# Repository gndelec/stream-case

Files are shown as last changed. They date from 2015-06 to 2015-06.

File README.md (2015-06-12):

# Myriad-RF STREAM board enclosure

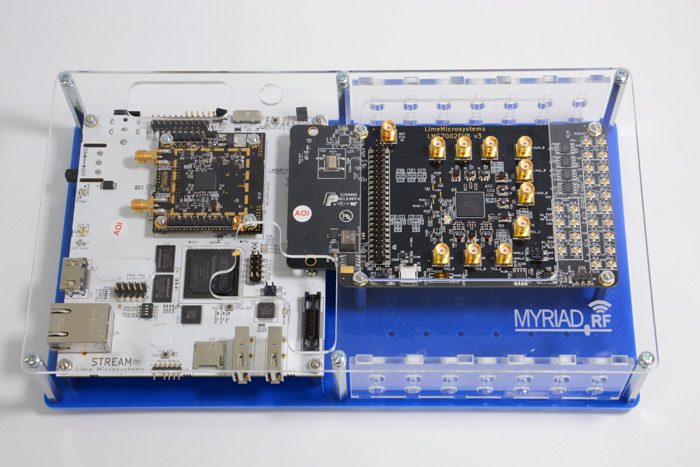
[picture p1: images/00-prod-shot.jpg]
MRFC-01 case


*Note: shown with 2x RF modules fitted, whereas only one at a time would be used in practice.*

An acrylic enclosure designed to accommodate the Myriad-RF STREAM board and an RF module. Features include:

* Hardware for secure mounting of boards
* Array of holes for panel mount SMA connectors
* Array of additional PEEK+ spaced holes for mounting other hardware

A complete kit of parts can be bought from [Ground Electronics](http://groundelectronics.com/products/).

## Repository contents

The case design is provided in the following formats:

* Inksacpe SVG (source)
* PDF
* DXF

The case parts are laser cut from 3mm sheet acrylic.

## Bill of materials

In addition to the acrylic parts the MRFC-01 kit contains:

| Qty | Item |
| --- | --- |
|  17 | M3 steel hex nut |
|  12 | M3 steel washer |
|  4  | M2.5 x 6mm steel machine screw |
|  2  | M2.5 x 15mm F-F hex standoff |
|  4  | M3 x 5mm F-F hex standoff |
|  4  | M3 x 15mm M-F hex standoff |
|  4  | M3 x 25mm M-F hex standoff |
|  6  | M3 x 40mm M-F hex standoff |
|  14 | M3 x 8mm steel machine screw |
|  4  | M3 x 12mm steel machine screw |
|  6  | Self Adhesive Rubber Bumpers |

## Other hardware required

- STREAM board
- [LMS7002EVB](http://www.digikey.co.uk/product-detail/en/UNITE7002/1434-1004-ND/5012881) or [Myriad-RF 1](https://myriadrf.org/projects/rdk/) module

## Assembly

Note that the STREAM board can be used standalone, or with an LMS7002EVB *or* Myriad-RF 1 module fitted. The photos in this repository show it with both of these fitted at the same time, however, this has not been tested and is not recommended! If using an RF module please following the instructions to fit one *or* the other.

### Common

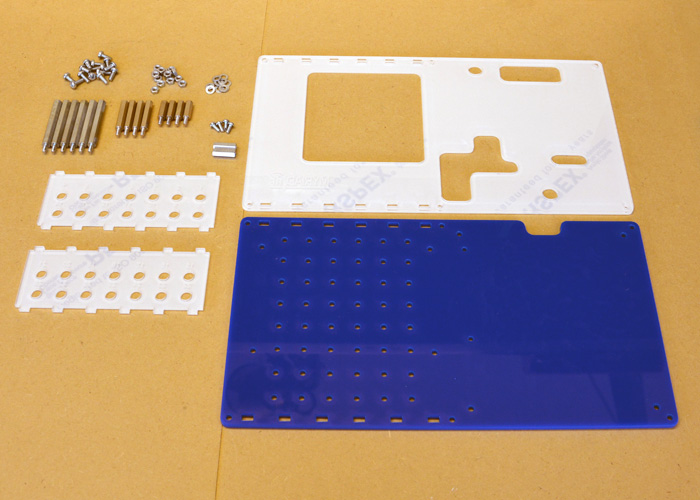
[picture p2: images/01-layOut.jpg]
Parts laid out


- Lay out all of the parts and ensure you have everything listed in the B.O.M.

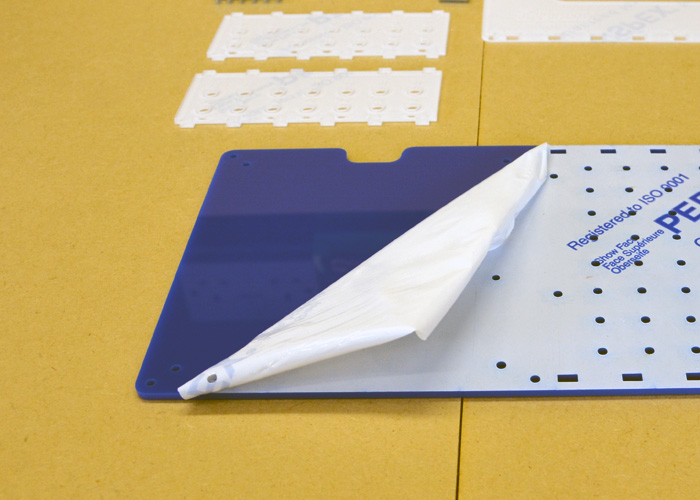
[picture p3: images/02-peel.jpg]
Peel off acrylic backing


- Remove the protective backing from the acrylic parts. Note that this is likely to generate static electricity and be not to do this near sensitive electronics. Wipe any clouding / marks from the acrylic that may have occured during manufacture.

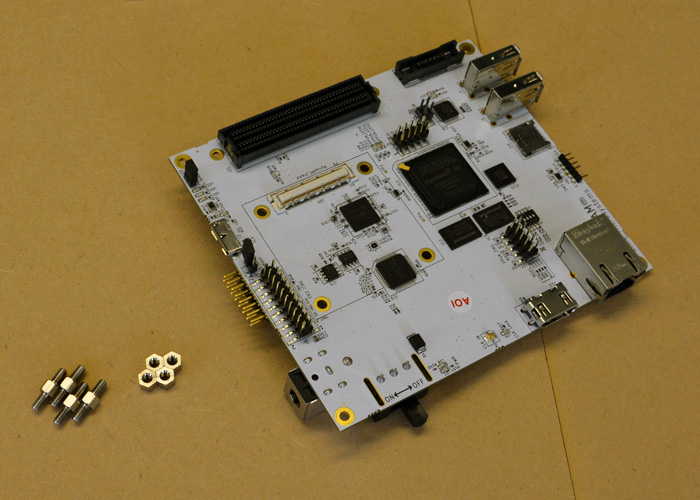
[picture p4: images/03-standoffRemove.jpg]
Standoff Remove


- Remove 4 x M3 x 4mm standoffs from STREAM board

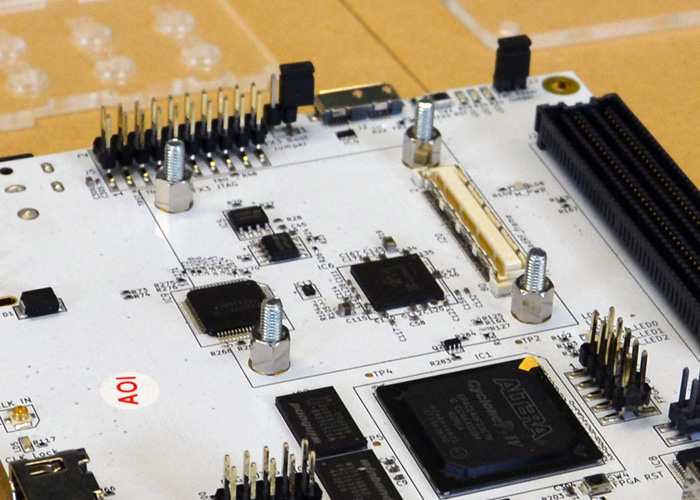
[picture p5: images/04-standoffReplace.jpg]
StandoffReplace


- Add 4 x M3 x 12mm screws + 4 x M3 x 5mm standoffs to replace the previous standoffs. Note M3 screws go through bottom of board, all the way through standoffs as shown in photo.

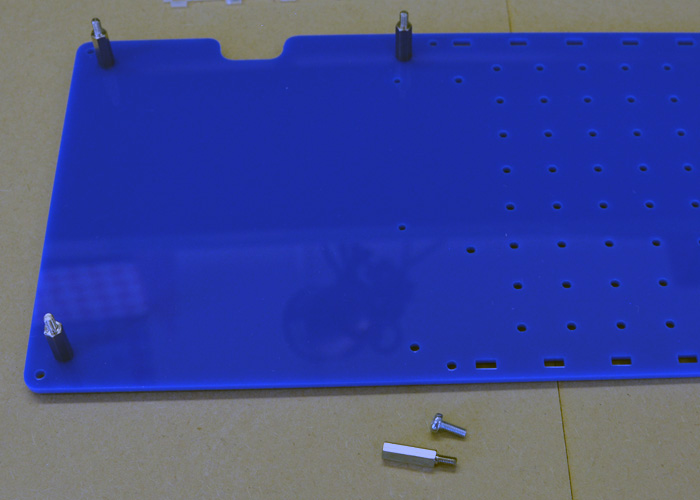
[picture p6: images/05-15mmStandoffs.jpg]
Standoffs


- Add 4 x M3 x 15mm M-F standoffs + 4 x M3 x 8mm screws to base.

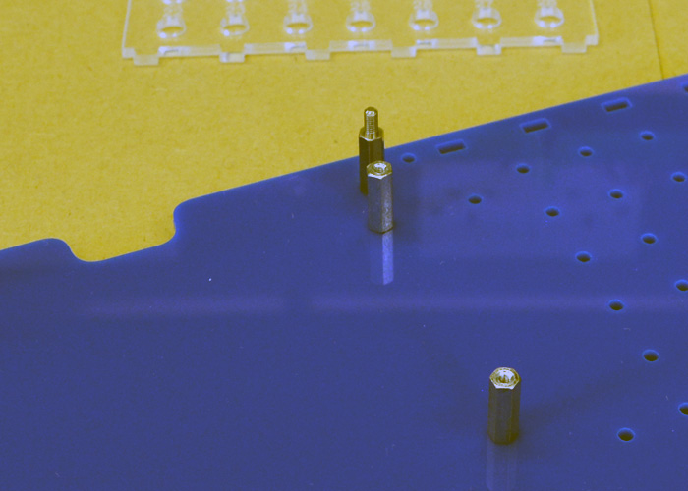
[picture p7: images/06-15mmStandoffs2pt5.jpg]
Standoffs


- Add 2 x M2.5 x 15mm F-F standoffs + 2 x M2.5 x 6mm screws to base.

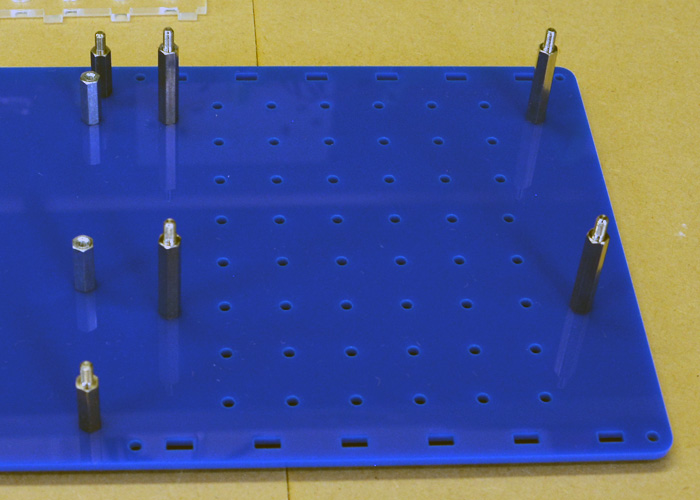
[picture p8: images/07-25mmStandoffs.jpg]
Standoffs


- Add 4 x M3 x 25mm M-F standoffs + 4 x M3 X 8mm screws to base.

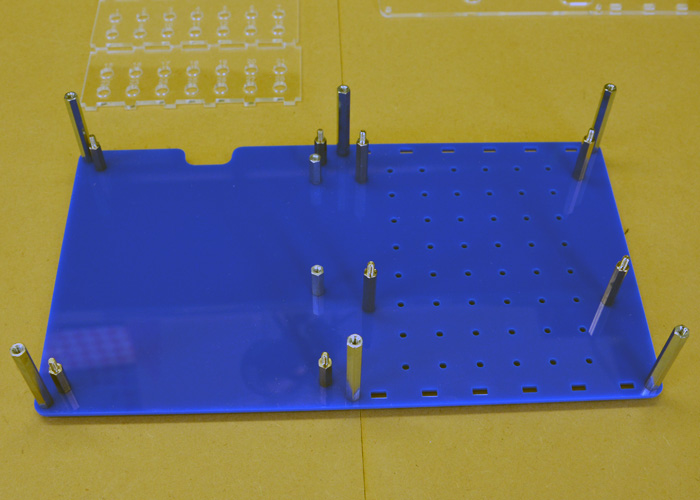
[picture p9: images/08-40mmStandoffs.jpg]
Standoffs


- Add 6 x M3 x 40mm standoffs + 6 x M3 hex nuts (Note these to be mounted opposite way up to other standoffs - male thread through base)

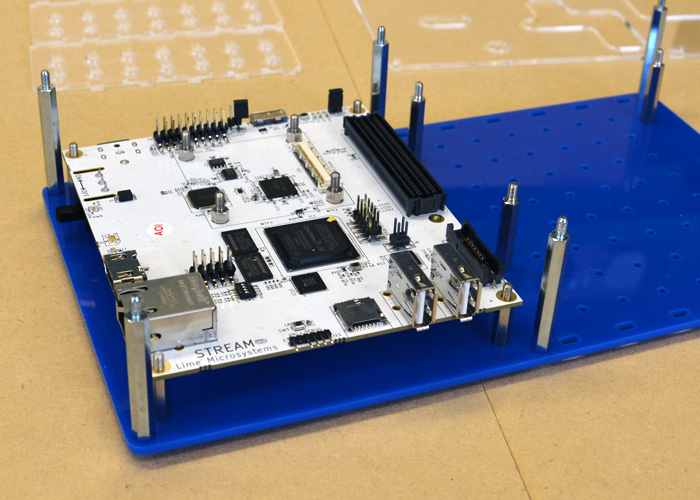
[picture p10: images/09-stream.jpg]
STREAM


- Place STREAM board onto 15mm standoffs.

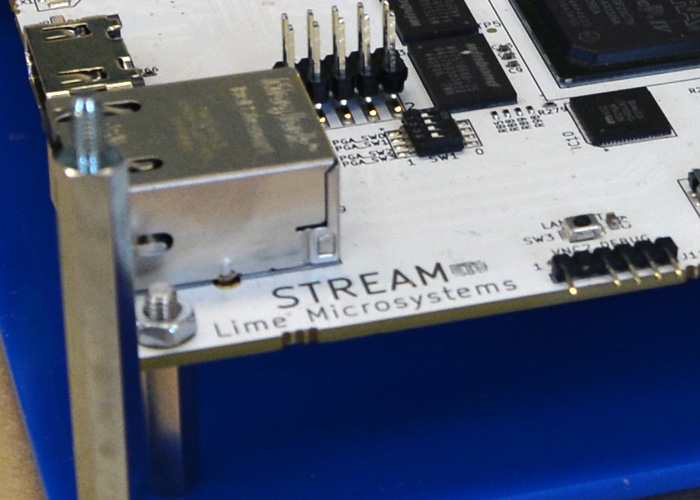
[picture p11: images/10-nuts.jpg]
nuts


- Add 4 x M3 hex nuts to hold STREAM board in place. Note to be careful not to overtighten.

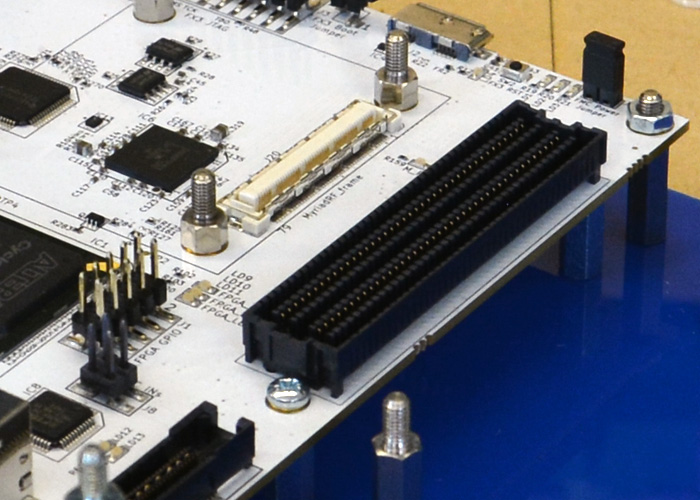
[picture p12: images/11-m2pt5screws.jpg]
screws


- Add 2 x M2.5 x 6mm screws through STREAM board, either side of the J21 connector.

** Note: The following steps are optional and which you follow will depend on which RF module you are using. Later photos show both boards fitted, but this has not been tested, is not advised and no responsibility will be accepted for any damage caused by applying power with both the LMS7002EVB and Myriad-RF 1 module fitted! **

### Use with LMS7002EVB (UNITE)

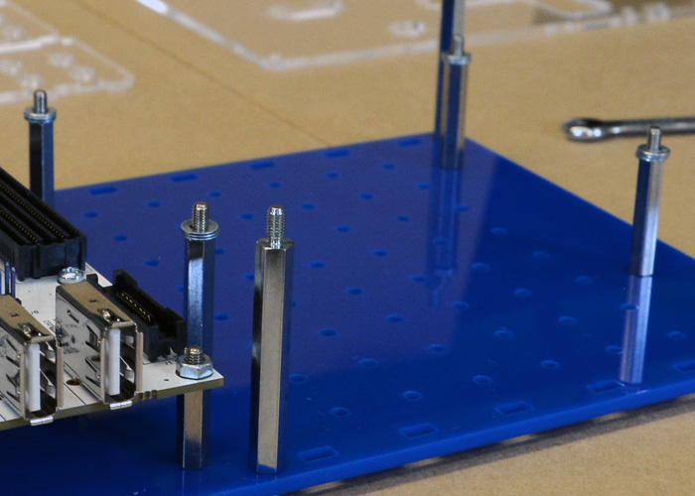
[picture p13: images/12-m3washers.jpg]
washers


- Add M3 washers to 4 x M3 x 25mm standoffs to get correct height for LMS7002EVB board (we found 2 or 3 per standoff to work well depending on the washers used).

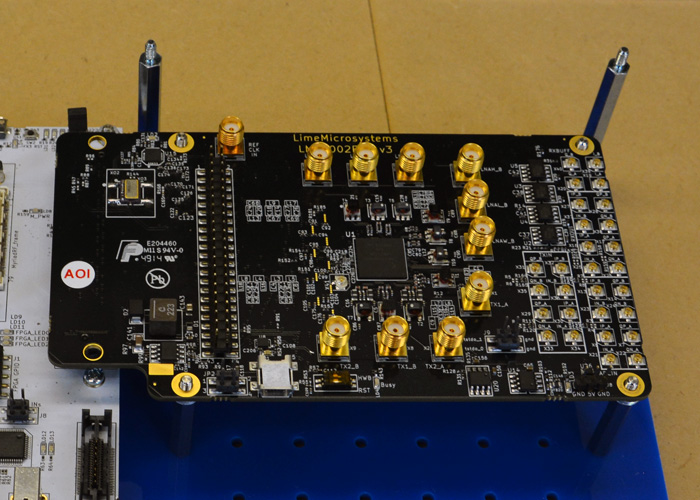
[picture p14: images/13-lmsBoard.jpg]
LMS7002EVB


- Add LMS7002EVB to M3 x 25mm standoffs + washers.

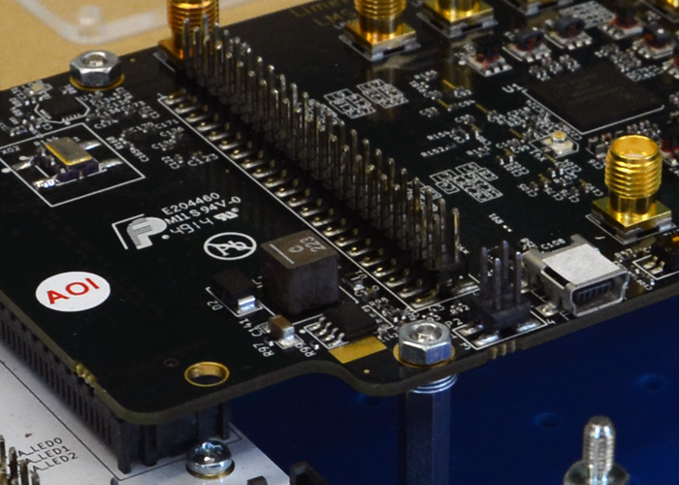
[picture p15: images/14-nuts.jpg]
nuts


- Add 4 x M3 hex nuts to hold LMS7002EVB in place. Again noting care to not overtighten.

### Use with Myriad-RF 1 module

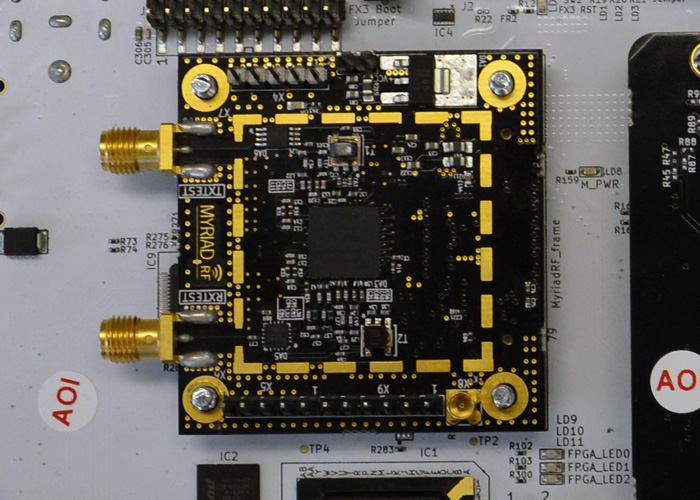
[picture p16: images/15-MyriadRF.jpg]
MyriadRF


- Add Myriad-RF module to STREAM board (Note that extra care should be taken due to the delicate nature of the connectors used)

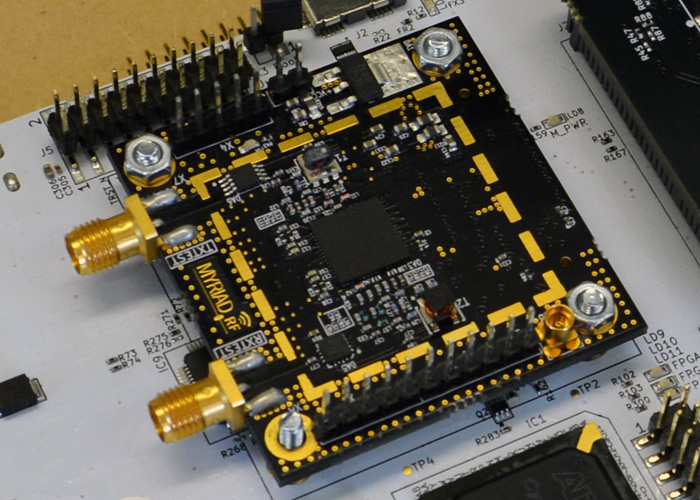
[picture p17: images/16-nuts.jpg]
nuts


- Add 3 x M3 hex nuts to hold Myriad-RF module in place (note that one corner does not allow for an M3 hex nut due insufficient clearance of nearby header)

### Completing case assembly

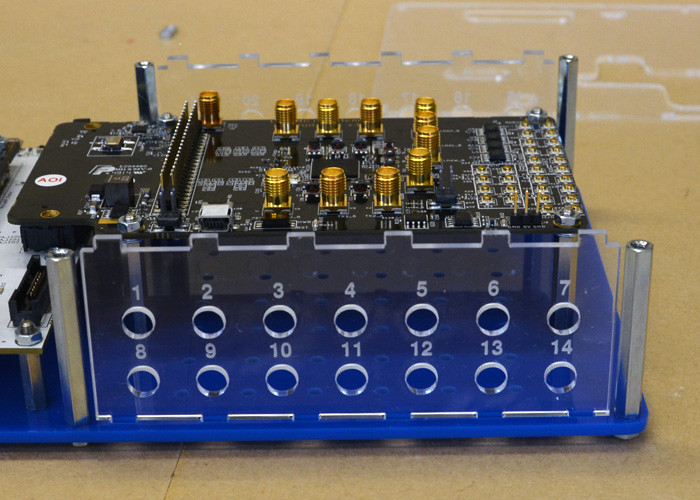
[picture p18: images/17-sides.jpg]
sides


- Add 2 x side pieces and optional breakout connectors / wire assemblies as needed (not included in kit)

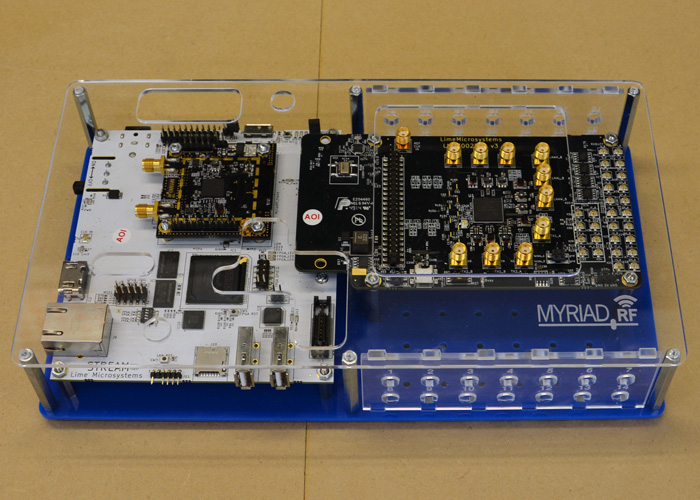
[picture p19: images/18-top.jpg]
top


- Add top plate to assembly

- Add 6 x M3 x 8mm screws to secure top plate in place.

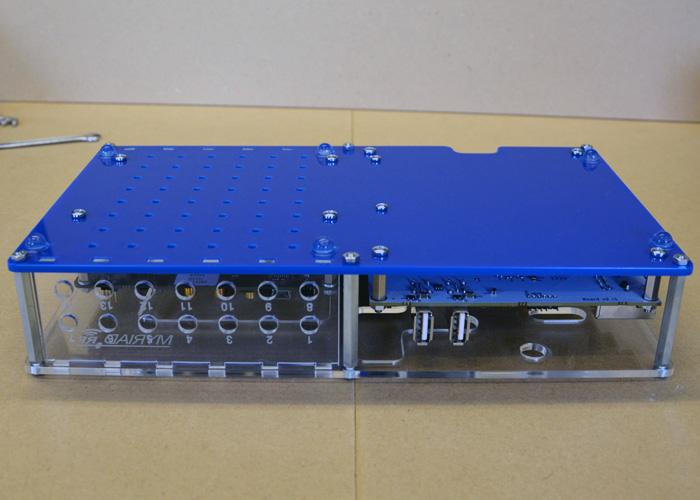
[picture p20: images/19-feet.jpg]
feet


- Turn the assembly over and stick the 6 x self adhesive rubber bumpers to the base.

## Notes

- The MRFC-01 case includes PEEK+ array (15mm) compatible hole spacing for easy addition of modules and hardware should you wish to exapnd your system. Note that we used 3mm holes to allow for use of M3 hardware and avoid the need for extra threaded push-fit parts.

- The MRFC-01 kit contains some extra units of the smaller hardware such as nuts and washers - do not be alarmed if there are some left over after completion of assembly!

## Changelog

| Version | Date | Summary
|---|---|---

## Licence

STREAM and Myriad-RF development case copyright 2015 [AB Open Ltd](http://abopen.com).

<br />This work is licensed under a <a rel="license" href="http://creativecommons.org/licenses/by/4.0/">Creative Commons Attribution 4.0 International License</a>.

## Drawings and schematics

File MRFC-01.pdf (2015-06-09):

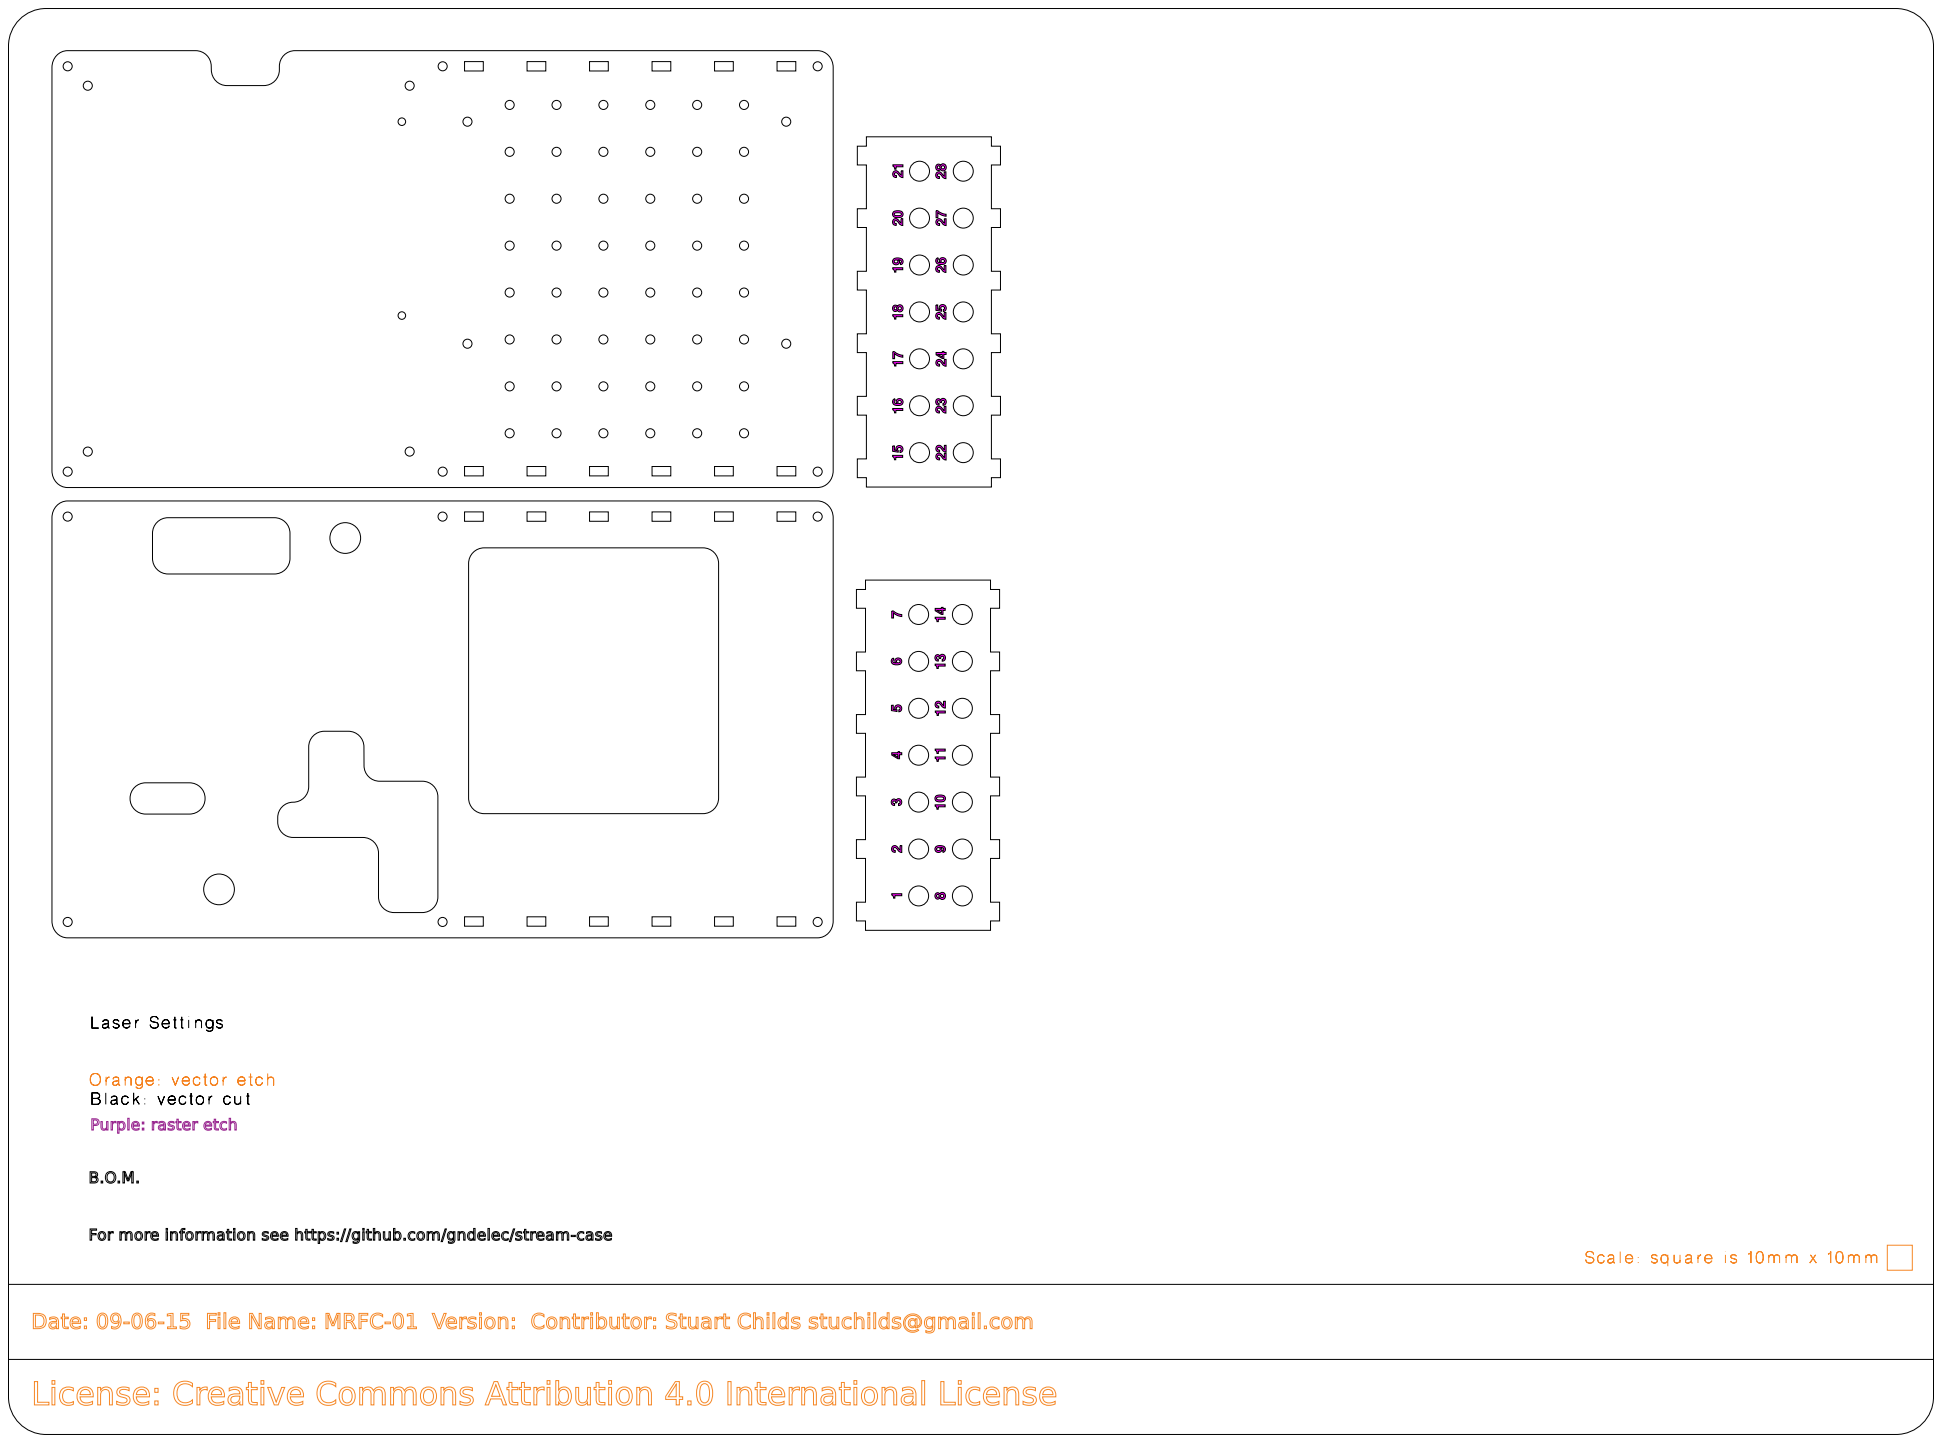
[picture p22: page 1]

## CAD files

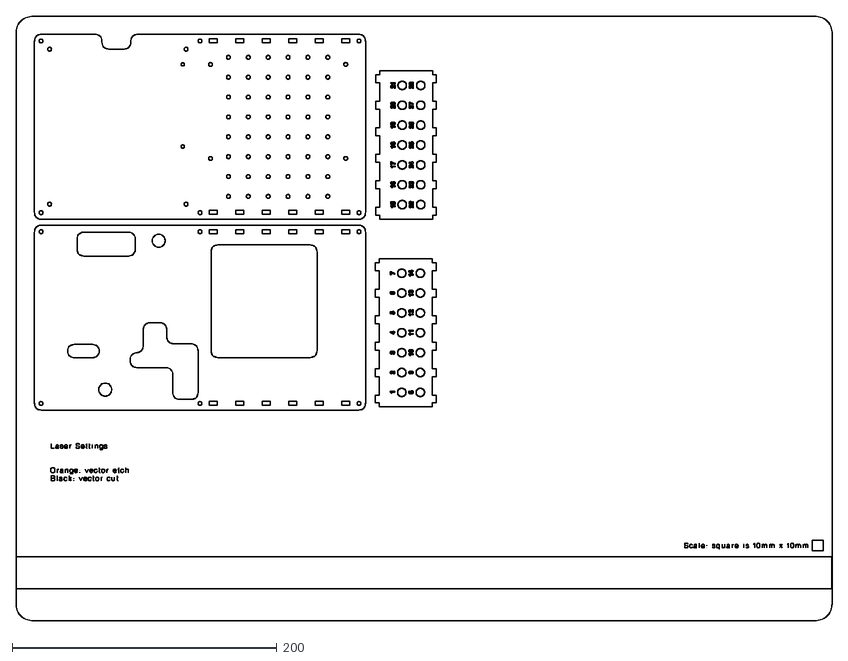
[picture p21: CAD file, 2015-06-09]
MRFC-01.dxf
616.0 x 456.0
